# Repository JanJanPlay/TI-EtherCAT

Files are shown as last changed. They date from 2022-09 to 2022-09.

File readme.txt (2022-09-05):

Please run the zip installer to obtain the below

 #1. SSC Tool Patches for C28x
		Note:- ETG SSC Tool patches for C28x MCU. This needs to be used if the SSC tool doesn't by default support the C28x config

 #2. Out of box Demo OUT file(s) 
		Note:- User will need to program the binary/COFF files on the ESC. 

Important Note:-

TMDSECATCNCD379D_EtherCAT_Solution_Ref
  - Please refer to SPRUIG9 user guide before building this CCS (Code Composer Studio) project.

  - Please note that this project will be built successfully only after user generates the EtherCAT slave stack sources using SSC tool and patches provided and moves them into the project. 
   The steps are explained in the SPRUIG9 user guide.

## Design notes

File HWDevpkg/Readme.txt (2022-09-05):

Release notes for Hardware files TMDSECATCNCD379D_V1.0
Date:- 09/30/2017.

This release requires two sets of Hardware board design.

EcAT adapter design includes in this folder 

and

Refer to the F28379D development kit folder for Controlcard design files

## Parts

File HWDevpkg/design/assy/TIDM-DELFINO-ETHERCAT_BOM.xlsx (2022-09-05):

Item | P/N | Vendor | Qty | Unit | ION Footprint | Type | Rev | Stat | Title | Detail | Mfr Name | Reference(m) | Reference(t) | Mfr P/N
1 | 518081-0001R |  | 1 | each |  | DWG | C | U | PWB,BOOSTXL-ETHERCAT | CSTM
2 | 518082-0001 |  | 1 | each |  | DOC | C | U | LOGIC,BOOSTXL-ETHERCAT | SCH
5 | 104671-0001R-TI |  | 1 | each | bga128-8mm | PS |  | U | IC,BGA128,.8mm,ETHERCAT SLAVE CONTROLLER | MATL | Beckhoff | U5 |  | ET1100
6 | 104684-0001R |  | 2 | each | VQFN32_202SQ | PS |  | U | IC,QFN32,SINGLE PORT 10/100Mbs ETHERNET PHY TRANSCEIVER,LOW POWER | MATL | Texas Instruments | U3, U6 |  | PDP83822RHBT
7 | 101670-0001R |  | 1 | each | tssop16-14x70 | PS |  | U | IC,QSOP16,LOW VOLTAGE,QUAD 2:1 MULTIPLEXER/DEMULTIPLEXER | MATL | Texas Instruments | U7 |  | SN74CBTLV3257PWR
8 | 101659-0001R |  | 1 | each | dbq20-14x70 | PS |  | U | IC,QSOP20,LOW VOLTAGE,QUICK SWITCH | MATL | Texas Instruments | U2 |  | SN74CBTLV3245ADBQR
9 | 101057-0007R |  | 1 | each | dck-5 | PS |  | U | IC,SO5,SINGLE BUFFER/DRIVER | MATL | Texas Instruments | U1 |  | SN74LVC1G07DCKR
10 | 104686-0001R |  | 1 | each | so8-25x75-295 | PS |  | U | IC,SO8,SERIAL EEPROM,16K-BIT | MATL | Catalyst Semiconductor, Inc. | U4 |  | CAT24C16WI-GT3
11 | 104063-0001R |  | 1 | each | dsg8-11x20 | PS |  | U | IC,SON8,STEP-DOWN DC-DC CONVERTER,1.6A,3.3V | MATL | Texas Instruments | U8 |  | TPS62063DSGT
14 | 103274-0025R |  | 1 | each | xtal4-47x51-ecx32 | PS |  | U | CRYSTAL,SMT,4 PIN,25MHz | MATL | ECS | Y1 |  | ECS-250-20-33-TR
15 | 100823-0001R |  | 2 | each | led1206-59x59 | PS |  | U | LED,SMT 1206,GREEN | MATL | LITEON | DS1, DS2 |  | LTST-C150GKT
16 | 104075-0100R |  | 1 | each | ind-LQH44p | PS |  | U | INDUCTOR,SMT,1uH | MATL | Murata Electronics | L2 |  | LQH44PN1R0NP0L
20 | 101858-2201R |  | 1 | each | l603-35x45 | PS |  | U | FERRITE BEAD,SMT 0603,220 OHM | MATL | Murata Electronics | L1 |  | BLM18AG221SN1D
25 | 103604-1472R |  | 2 | each | C1206-40X70 | PS |  | U | CAP,CER,SMT 1206,4700pF,200V,+10/-10%,X7R | MATL | AVX Corporation | C41, C83 |  | 12062C472KAT2A
26 | 101064-0221R |  | 2 | each | C1206-40X70 | PS |  | U | CAP,CER,SMT 1206,22uF,10V | MATL | Taiyo Yuden | C4, C6 |  | LMK316F226ZL-T
27 | 101007-0100R |  | 8 | each | c603-35x45 | PS |  | U | CAP,CER,SMT 0603,1uF,6.3V,X5R,+/-10% | MATL | Murata Electronics | C12, C14, C15, C33, C55, C58, C77, C82 |  | GRM188R60J105KA01D
28 | 102963-0101R |  | 8 | each | c603-35x45 | PS |  | U | CAP,CER,SMT 0603,10uF,6.3V,X5R,+/-20% | MATL | Murata Electronics | C22, C26, C34, C38, C44, C74, C78, C80 |  | GRM188R60J106ME47D
29 | 101782-1223R |  | 15 | each | c402-25 | PS |  | U | CAP,CER,SMT 0402,220pF,50V,NPO | MATL | Murata Electronics | C2, C27, C28, C30, C31, C43, C46, C49, C52, C57, C63, C64, C66, C67, C81 |  | GRM1555C1H221JA01D
30 | 101782-1154R |  | 2 | each | c402-25 | PS |  | U | CAP,CER,SMT 0402,15pF,50V,NPO | MATL | Yageo | C3, C7 |  | CC0402JRNPO9BN150
31 | 101782-1103R |  | 2 | each | c402-25 | PS |  | U | CAP,CER,SMT 0402,100pF,50V,+/-5%,NPO | MATL | Kemet Electronics Corporation | C1, C37 |  | C0402C101J5GAC
32 | 101782-1102R |  | 5 | each | c402-25 | PS |  | U | CAP,CER,SMT 0402,1000pF,50V,+/-5%,NPO | MATL | TDK Corporation | C8, C25, C32, C73, C76 |  | CGJ2B2C0G1H102J
33 | 104446-1100R |  | 35 | each | c402-25 | PS |  | U | CAP,CER,SMT 0402,.1uF,16V,+/-10%,X7R,AUTOMOTIVE | MATL | Murata Electronics | C5, C9, C10, C11, C13, C16, C17, C19, C20, C21, C23, C29, C35, C36, C39, C40, C42, C45, C47, C48, C50, C51, C53, C54, C56, C59, C60, C62, C65, C68, C69, C70, C71, C75, C79 |  | GCM155R71C104KA55
34 | 101587-1101R |  | 4 | each | c402-25 | PS |  | U | CAP,CER,SMT 0402,.01uF,16V,+/-10%,X7R | MATL | Kemet Electronics Corporation | C18, C24, C61, C72 |  | C0402C103K4RAC
40 | 103158-2202R |  | 18 | each | r201-6p6spc | PS |  | U | RES,SMT 0201,2.2K OHM,5%,1/20 WATT | MATL | Yageo | R15, R16, R17, R22, R30, R32, R36, R37, R41, R48, R49, R50, R52, R54, R57, R62, R63, R69 |  | RC0201JR-072K2L
41 | 101370-0001R |  | 2 | each | r402-25 | PS |  | U | RES,SMT 0402,0 OHM,1/16 WATT | MATL | Yageo | RJ1, RJ2 |  | RC0402JR-070RL
42 | 102145-1003R |  | 2 | each | r402-25 | PS |  | U | RES,SMT 0402,10K,1%,1/16 WATT | MATL | Yageo | R1, R8 |  | RC0402FR-0710KL
43 | 102145-1103R |  | 1 | each | r402-25 | PS |  | U | RES,SMT 0402,11K OHM,1%,1/16 WATT | MATL | Panasonic | R19 |  | ERJ-2RKF1102X
44 | 102145-4702R |  | 20 | each | r402-25 | PS |  | U | RES,SMT 0402,4.7K,1%,1/16 WATT | MATL | Vishay Intertechnology | R13, R18, R20, R24, R25, R26, R27, R28, R33, R34, R42, R44, R45, R46, R47, R59, R66, R67, R68, R73 |  | CRCW04024K70FKED
45 | 102145-4872R |  | 2 | each | r402-25 | PS |  | U | RES,SMT 0402,4.87K,1%,1/16 WATT | MATL | Panasonic | R40, R65 |  | ERJ-2RKF4871X
46 | 102145-4990R |  | 14 | each | r402-25 | PS |  | U | RES,SMT 0402,49.9 OHM,1%,1/16 WATT | MATL | Panasonic | R2, R3, R4, R5, R6, R7, R9, R10, R11, R12, R39, R58, R70, R71 |  | ERJ-2RKF49R9X
47 | 100687-4701R |  | 6 | each | r603-35X45 | PS |  | U | RES,SMT 0603,470 OHM,5%,1/16 WATT | MATL | Panasonic | R14, R43, R51, R72, R74, R75 |  | ERJ-3GEYJ471V
50 | 101184-0002R |  | 1 | each | sw2-30x50-tda | PS |  | U | SWITCH,DIP,SMT,HALF-PITCH,2 POS. | MATL | C&K/Unimax, Inc. | SW1 |  | TDA02H0SB1R
55 | 104687-0060R |  | 1 | each | df40c_60ds | PS |  | U | CONN,SMT,RECEPTACLE,60 POS.,.4mm SPC.,4mm STACKING HEIGHT | MATL | Hirose Electric, Inc. | J6 |  | DF40HC-(4.0)60DS-0.4V
57 | 104401-0001R |  | 2 | each | RJ45-PULSE_J1-SHLD | PS |  | U | CONN,JACK,RJ45,INTEGRATED MAGNETICS AND LED'S,8 CONTACTS,SHIELDED | MATL | Pulse Engineering | P1, P0 |  | J1011F01PNL
58 | 100546-0003R |  | 2 | each | hdr1x3-6040-2mm | PL |  | U | HEADER,3 X 1,VERTICAL,2mm | SUBA | Harwin | J3, J10 |  | M22-2510305
60 | 104178-0001R |  | 1 | each | TP1-70X135 | PS |  | U | TEST POINT,SMT,MINIATURE | MATL | Keystone Electronics Corp. | TP15 |  | 5015
65 | SMT-TP030 |  | 11 | each | tp30 | PS |  | U | ( NO-POP ) TEST POINT,SMT,.03" DIA. | NP | None | TP2, TP3, TP4, TP5, TP6, TP7, TP9, TP11, TP13, TP14, TP16 |  | None
70 | R0201-NOPOP |  | 10 | each | r201-6p6spc | PS |  | U | (NO-POP) RES,SMT 0201 | NP | None | R23, R29, R31, R35, R38, R53, R55, R56, R61, R64 |  | None
75 | R0402-NOPOP |  | 2 | each | r402-25 | PS |  | U | (NO-POP) RES,SMT 0402 | NP | None | R21, R60 |  | None
80 | TP-40RD20-NO-POP |  | 4 | each | tp1-4020 | PS |  | U | (NO-POP) TEST POINT | NP | None | TP1, TP8, TP10, TP12 |  | None
81 | 104699-0002R |  | 1 | each | conn2-eh | PS |  | U | CONN,HEADER,SHROUDED,2 POS | MATL | JST Corporation | J9 |  | B2B-EH-A(LF)(SN
82 | 100542-0001R |  | 2 | each |  | PS |  | U | JUMPER,SHUNT,2mm | MATL | Sullins Electronics, Corp. |  |  | SPN02SYBN-RC

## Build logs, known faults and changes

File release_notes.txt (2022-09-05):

Release notes for Software included in TMDSECATCNCD379D_V1.0

Date:- 09/29/2017

Documents:-
	 1. SPRUIF9.pdf - HW, Demo and PDI HAL API TEST APP Getting started guide
  	 2. SPRUIG9.pdf - TMDSECATCND379D EtherCAT Solution Reference guide

Deliverables:- 

	 1. PDI HAL Test APP for TMDSECATCNCD379D 
		Note:- Code Composer Studio project

	 2. EtherCAT solution reference project 
		Note:- For users to do source level debug with ETG SSC tool generated EtherCAT slave stack sources. Before building this project please read SPRUIG9.pdf

	 3. SSC(Slave Stack code) Tool Patches for C28x
		Note:- ETG(EtherCAT Technology group) SSC Tool patches for C28x MCU. This needs to be used if the SSC tool doesn't by default support the C28x config

	 4. Out of box Demo OUT file(s) 
		Note:- User will need to program the binary/COFF files on the ESC. 
		Please read SPRUIF9 on how to use the DEMO files.

Note:- Deliverables 3 and 4 are obtained by running the zip installer available in the folder.		

EtherCAT slave stack features supported in this release:- 
	 1. COE Mailbox support for data exchange
	 2. Conformance Test Tool run on the demo application
	 3. TwinCAT EtherCAT master running on a laptop is used as EtherCAT master.
 
Build Environment:-
	Slave Stack code base line :-  v5.11
	CCS compiler version :- 16.12.x
	CTT tool version used for test :- 2.0.42.0
		Test Library version:- 1.1.0.0

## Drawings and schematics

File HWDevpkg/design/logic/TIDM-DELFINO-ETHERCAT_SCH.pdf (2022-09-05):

J10 DEFAULT JUMPER POP | 1-2
J3 DEFAULT JUMPER POP | 1-2

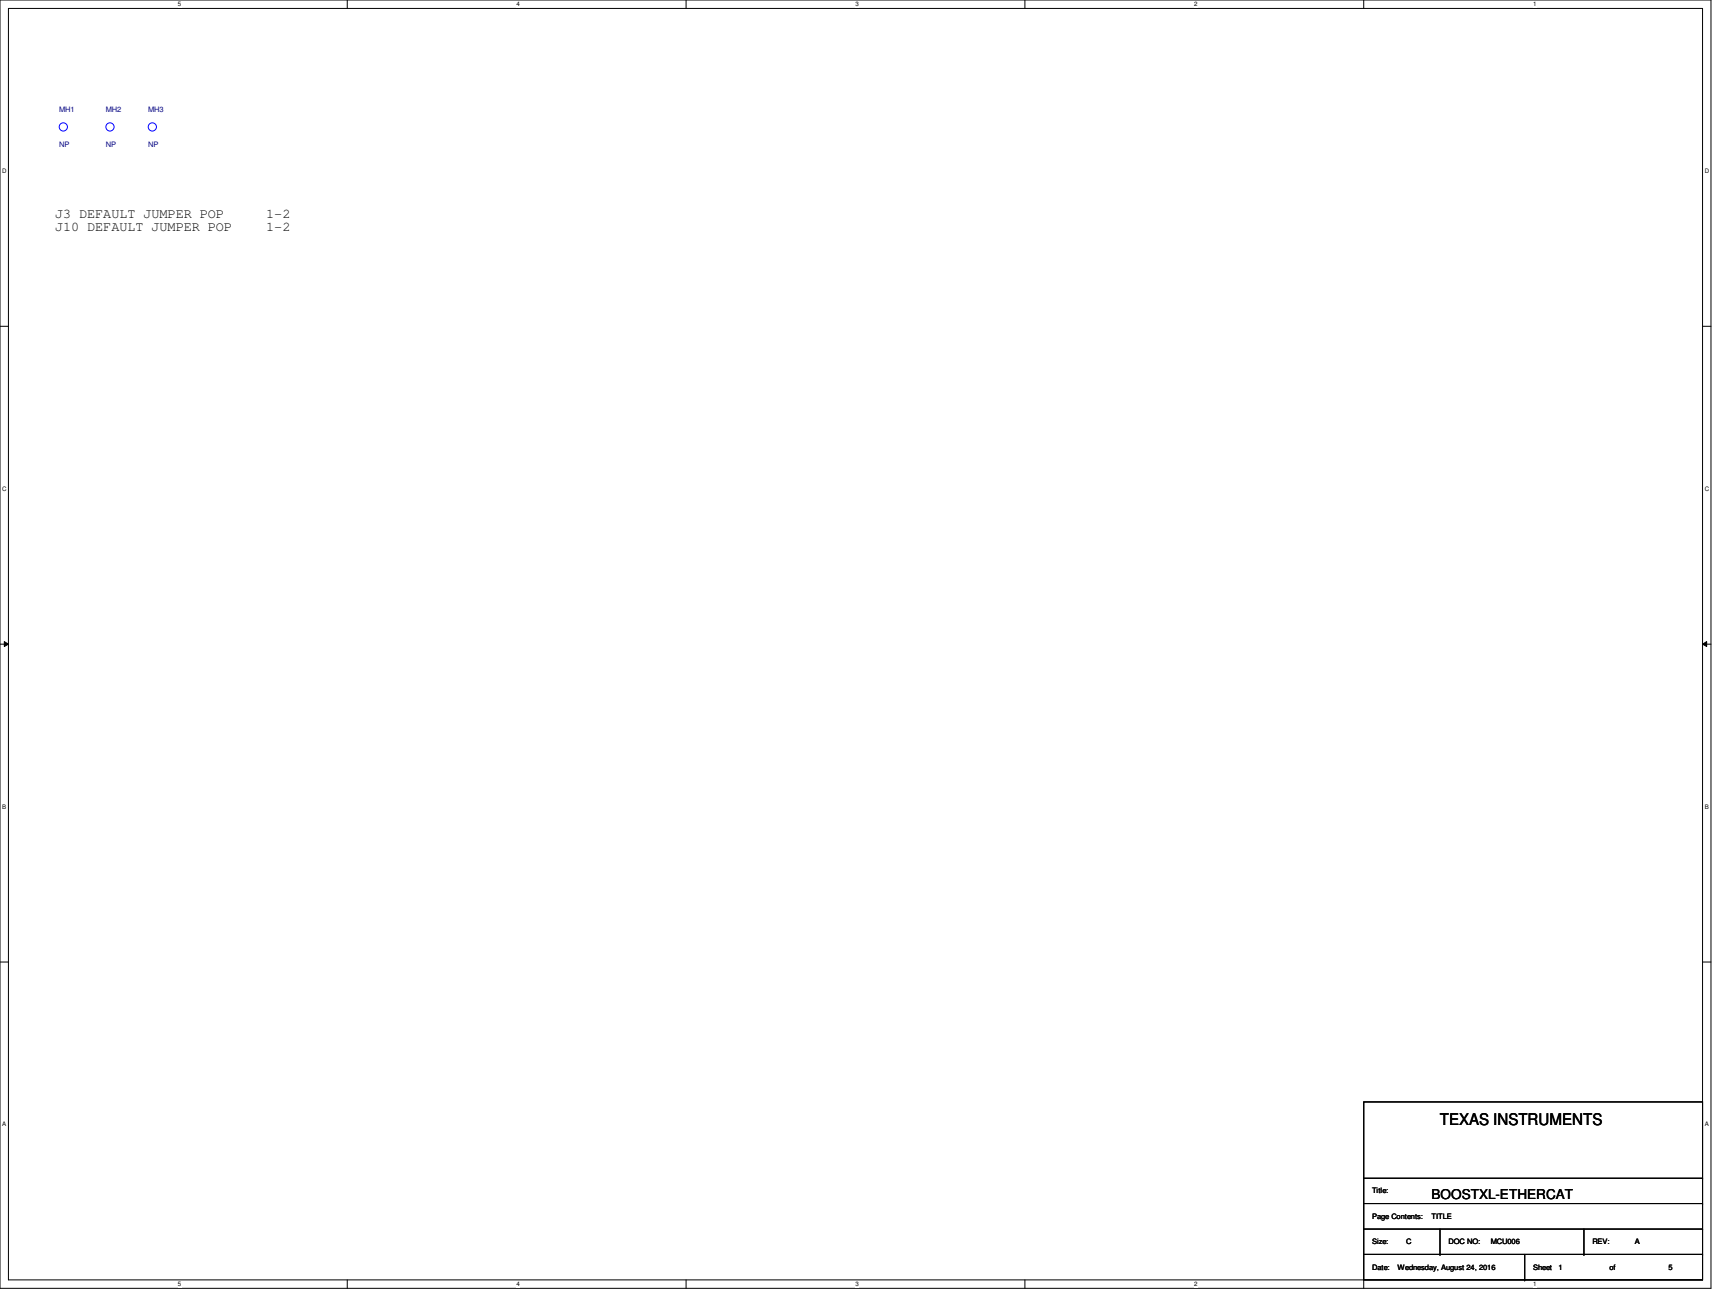
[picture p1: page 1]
Title:; Page Contents:; Size:; DOC NO:; REV:; Date:; Sheet; TEXAS INSTRUMENTS; BOOSTXL-ETHERCAT; TITLE; Wednesday, August 24, 2016; MCU006

## CONTROL CARD SPI/EMIF CONNECTIONS

## SPI vs EMIF POPULATIONS

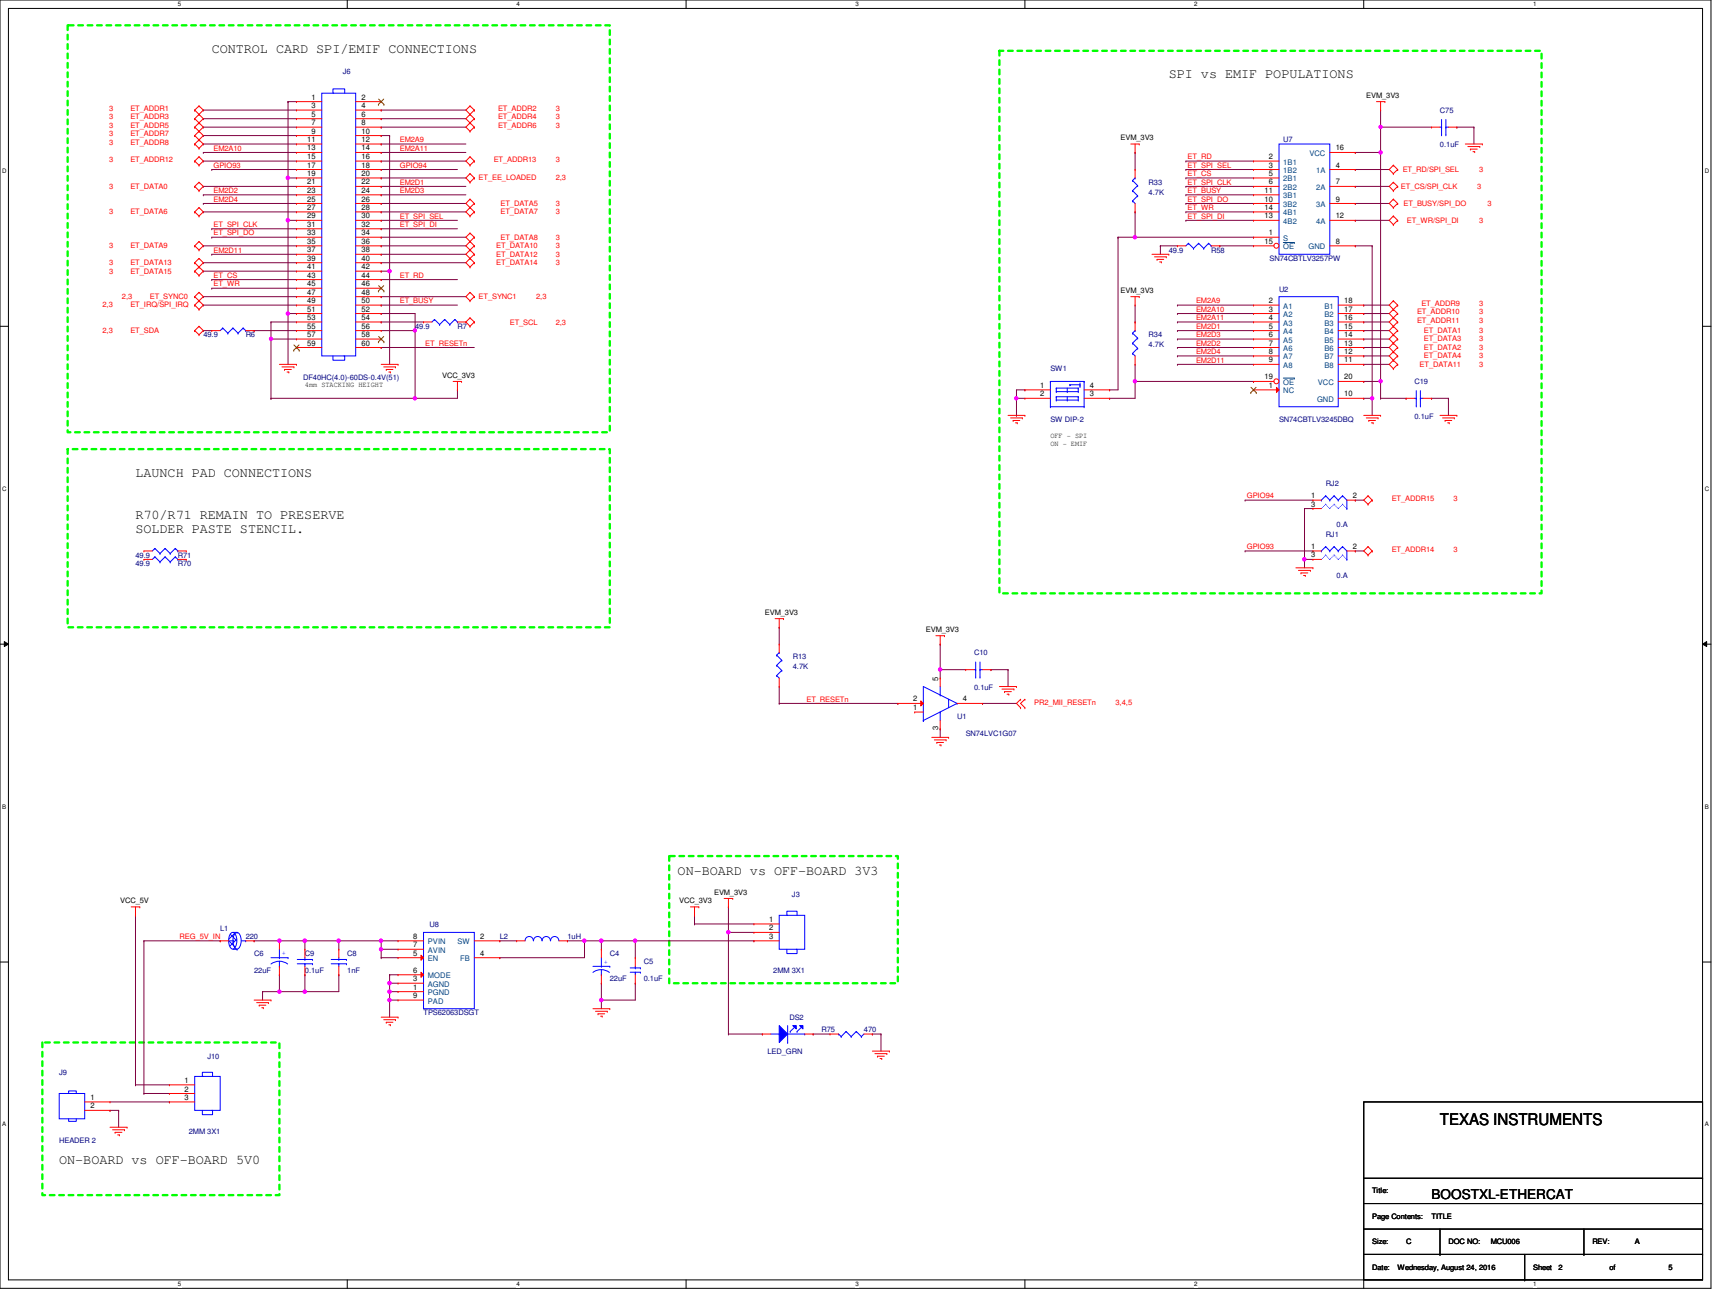
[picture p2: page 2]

ON-BOARD vs OFF-BOARD 3V3

HEADER 2
ON-BOARD vs OFF-BOARD 5V0

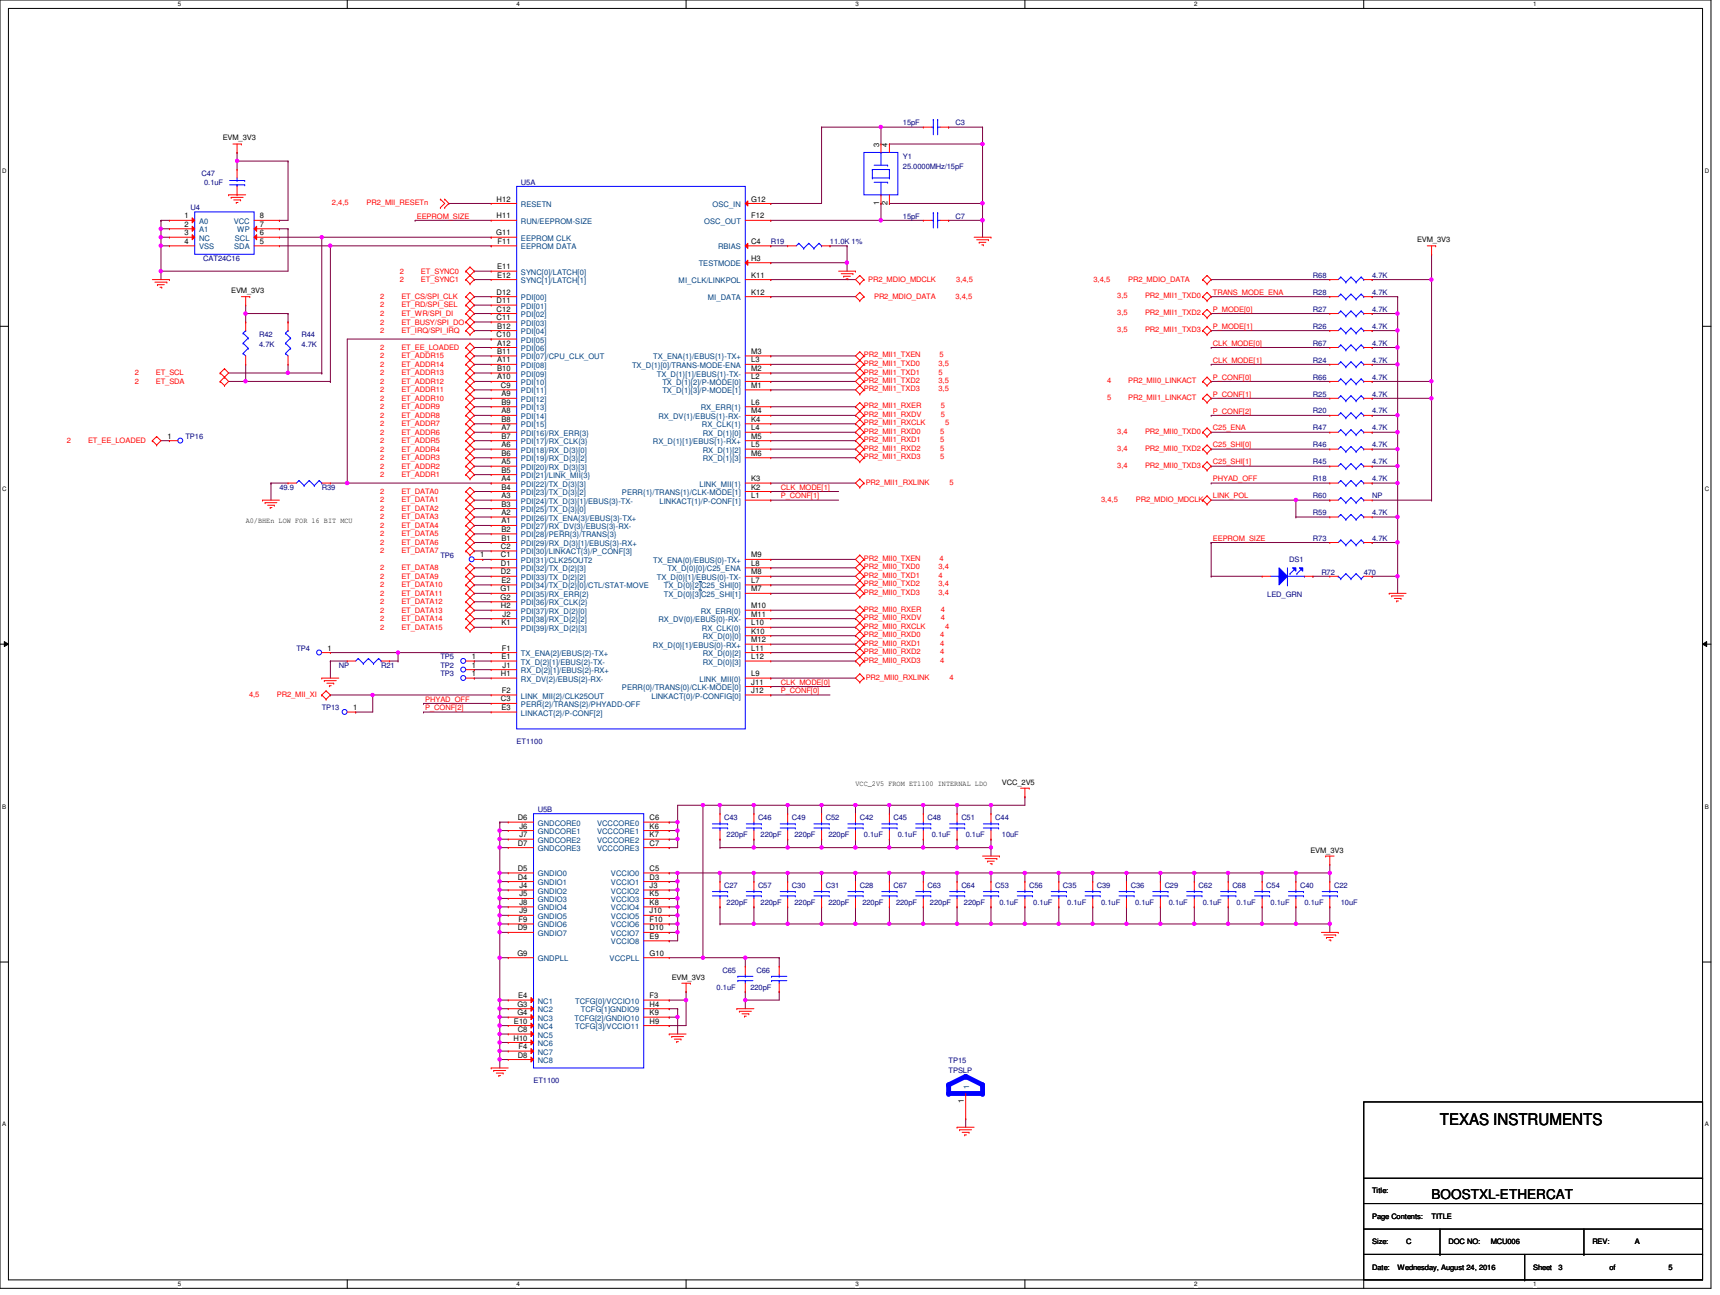
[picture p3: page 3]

A0/BHEn LOW FOR 16 BIT MCU

LINK_MII{2}/CLK25OUT F2
PERR{2}/TRANS{2}/PHYADD-OFF C3
LINKACT{2}/P-CONF[2] E3

# PORT 0: IN

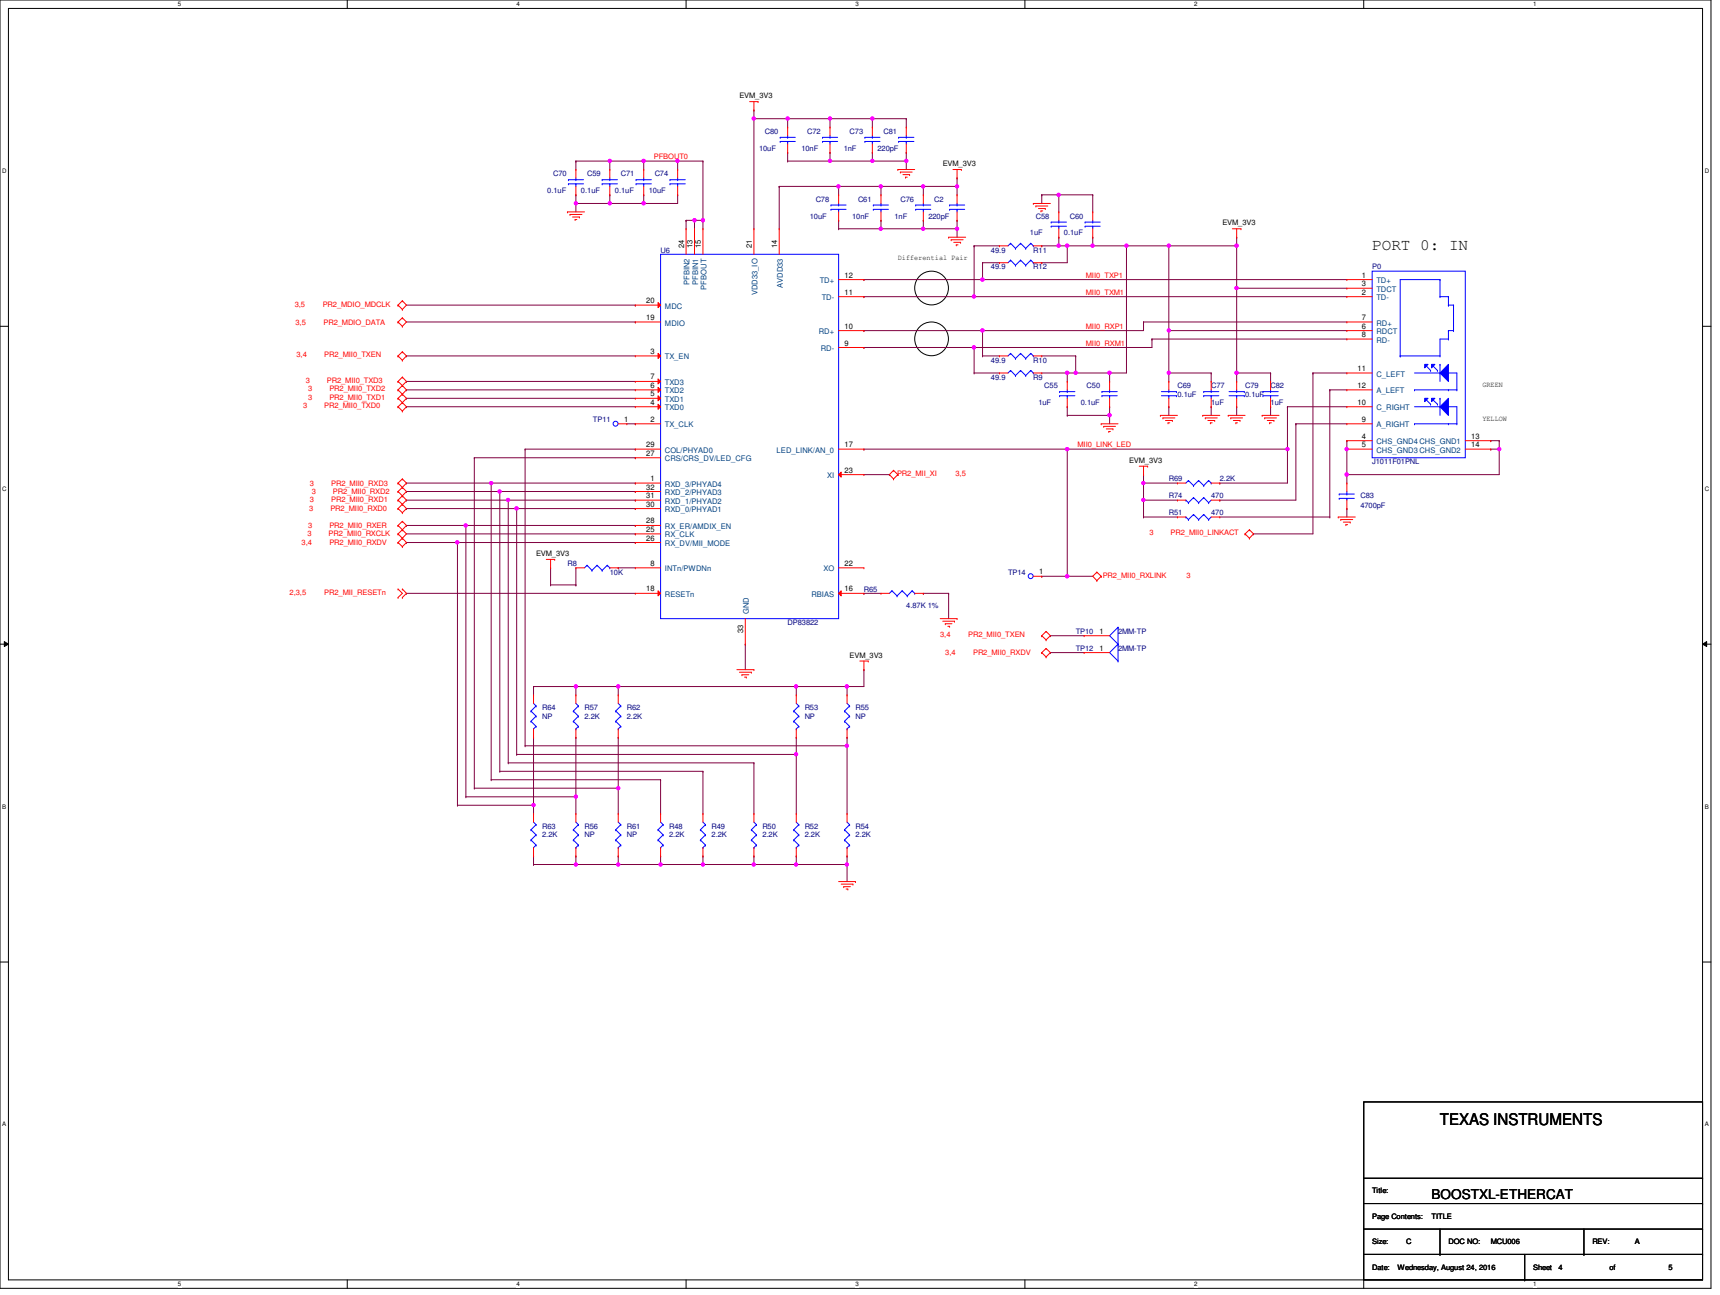
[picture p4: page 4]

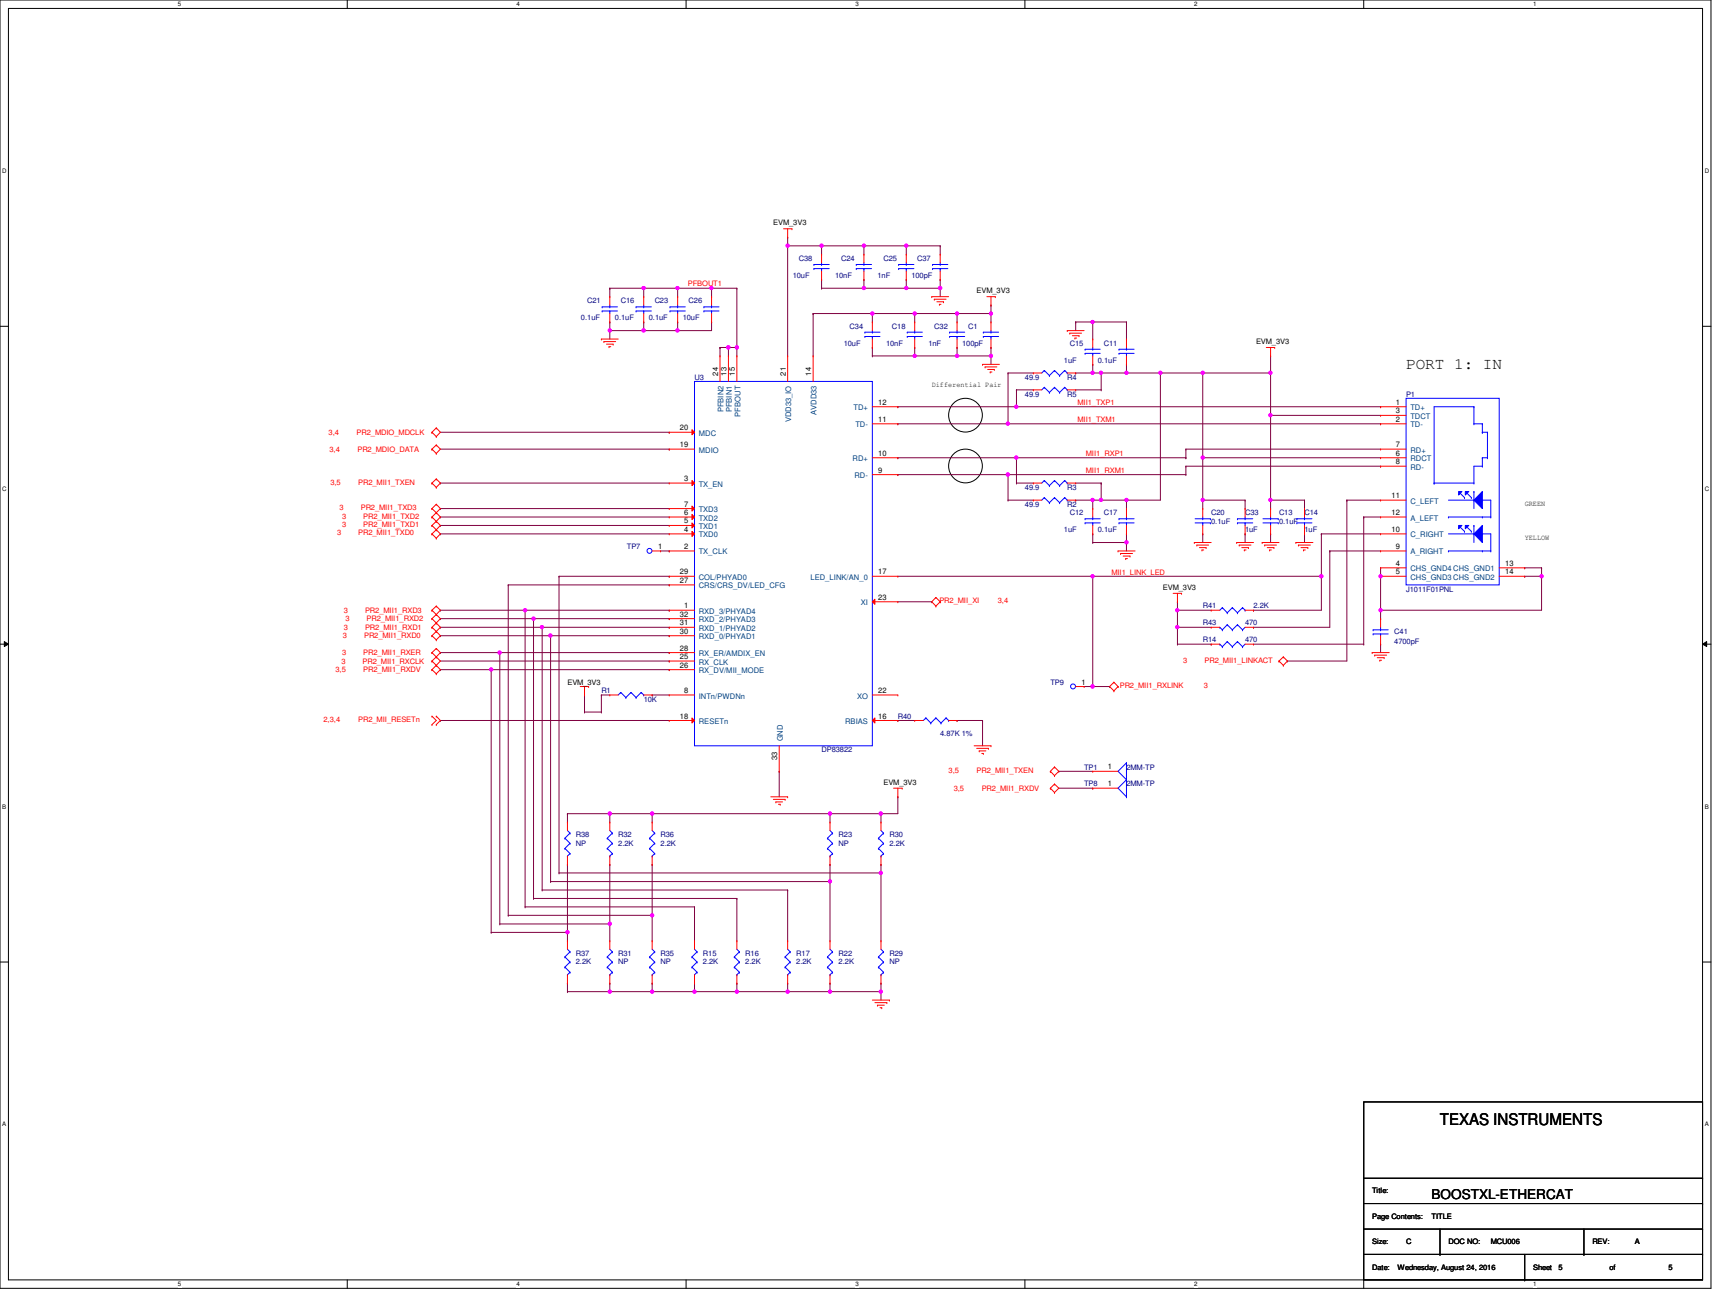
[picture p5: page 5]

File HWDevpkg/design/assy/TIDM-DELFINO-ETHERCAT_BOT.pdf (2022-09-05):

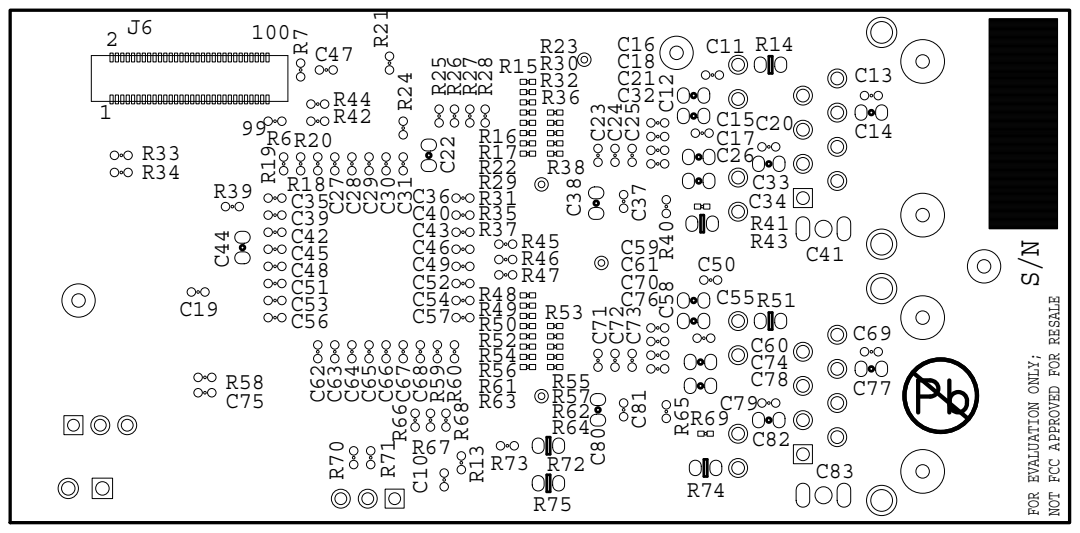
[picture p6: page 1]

NOT FCC APPROVED FOR RESALE

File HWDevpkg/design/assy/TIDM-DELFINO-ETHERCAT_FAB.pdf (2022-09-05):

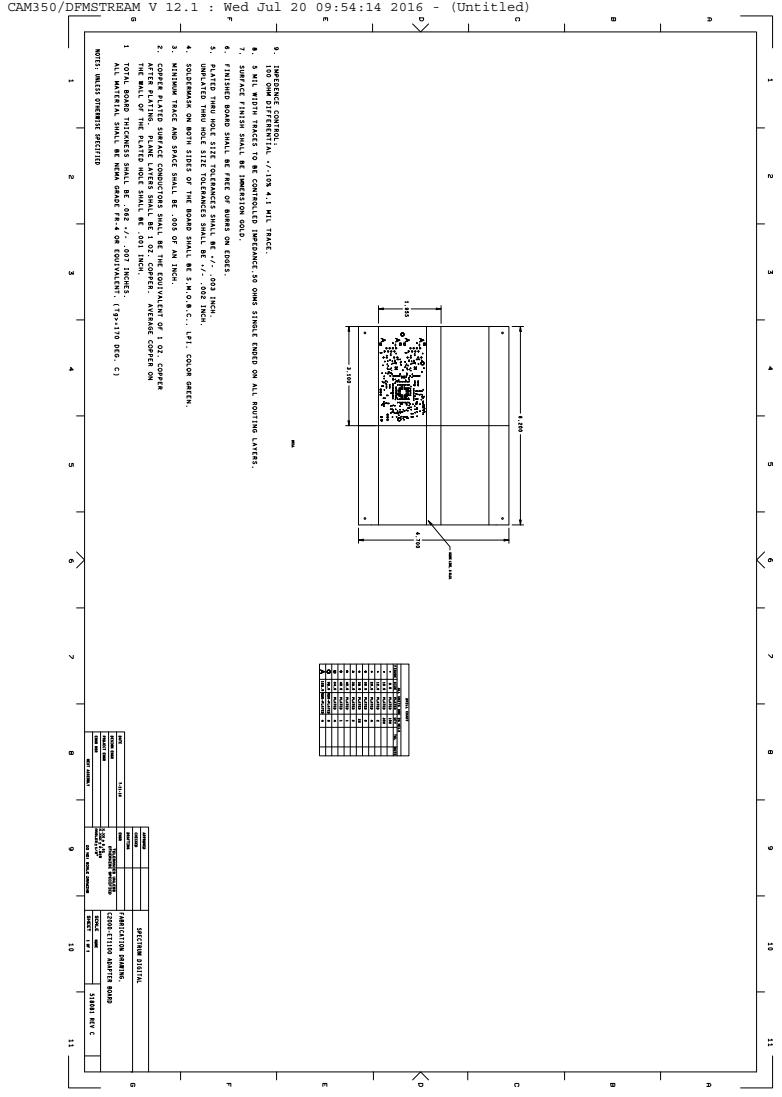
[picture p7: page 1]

CAM350/DFMSTREAM V 12.1 : Wed Jul 20 09:54:14 2016 - (Untitled)

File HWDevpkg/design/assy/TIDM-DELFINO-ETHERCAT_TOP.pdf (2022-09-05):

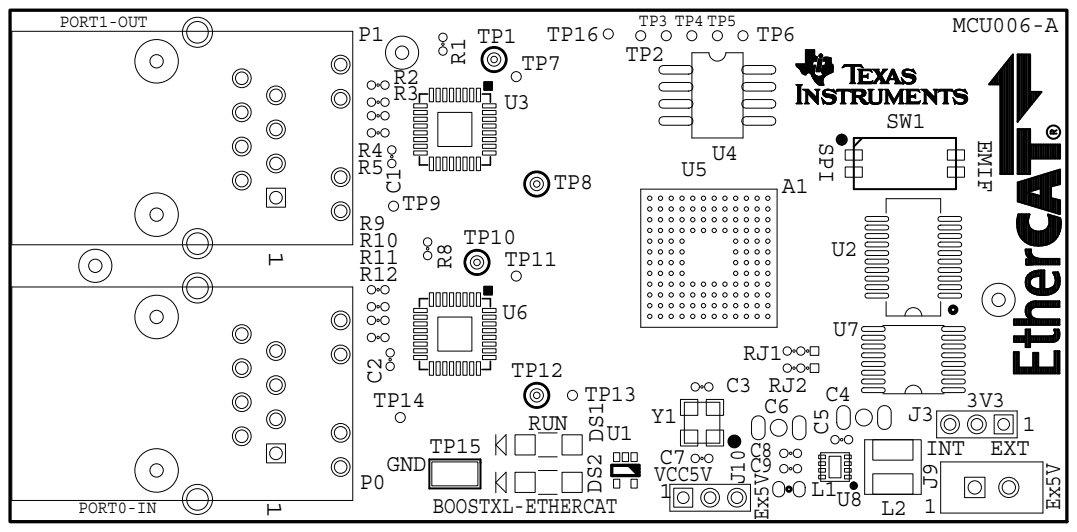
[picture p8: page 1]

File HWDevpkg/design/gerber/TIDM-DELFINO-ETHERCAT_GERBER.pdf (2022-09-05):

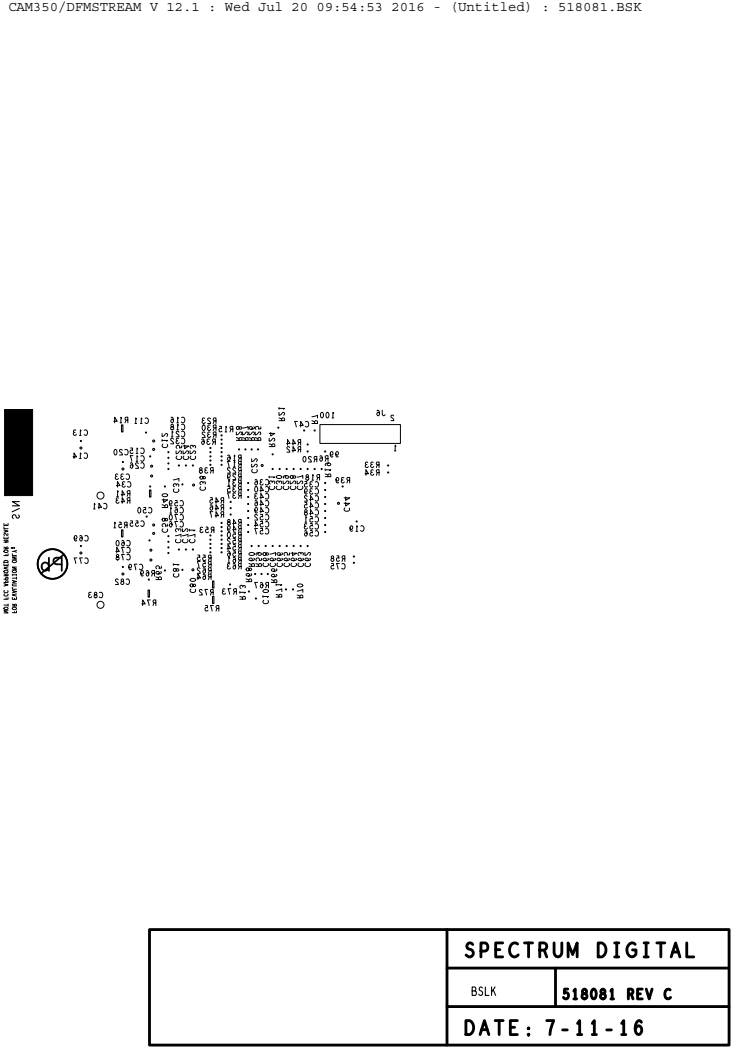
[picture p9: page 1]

CAM350/DFMSTREAM V 12.1 : Wed Jul 20 09:54:53 2016 - (Untitled) : 518081.BSK

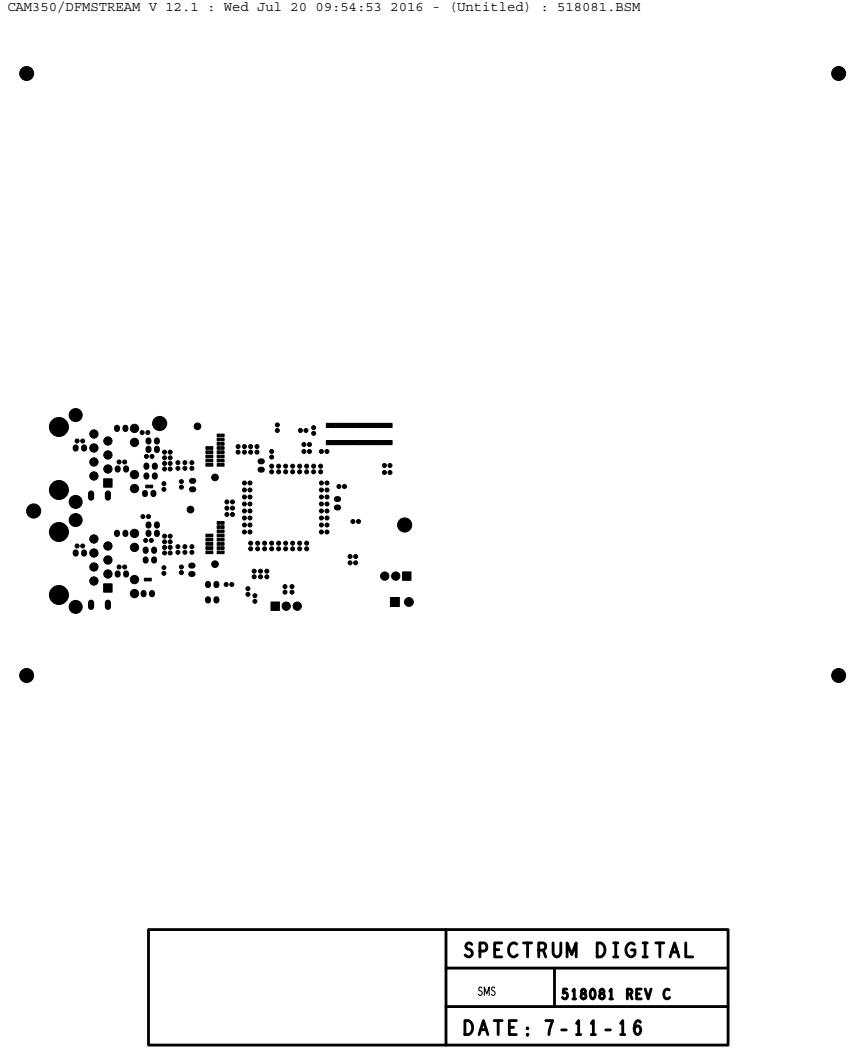
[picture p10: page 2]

CAM350/DFMSTREAM V 12.1 : Wed Jul 20 09:54:53 2016 - (Untitled) : 518081.BSM

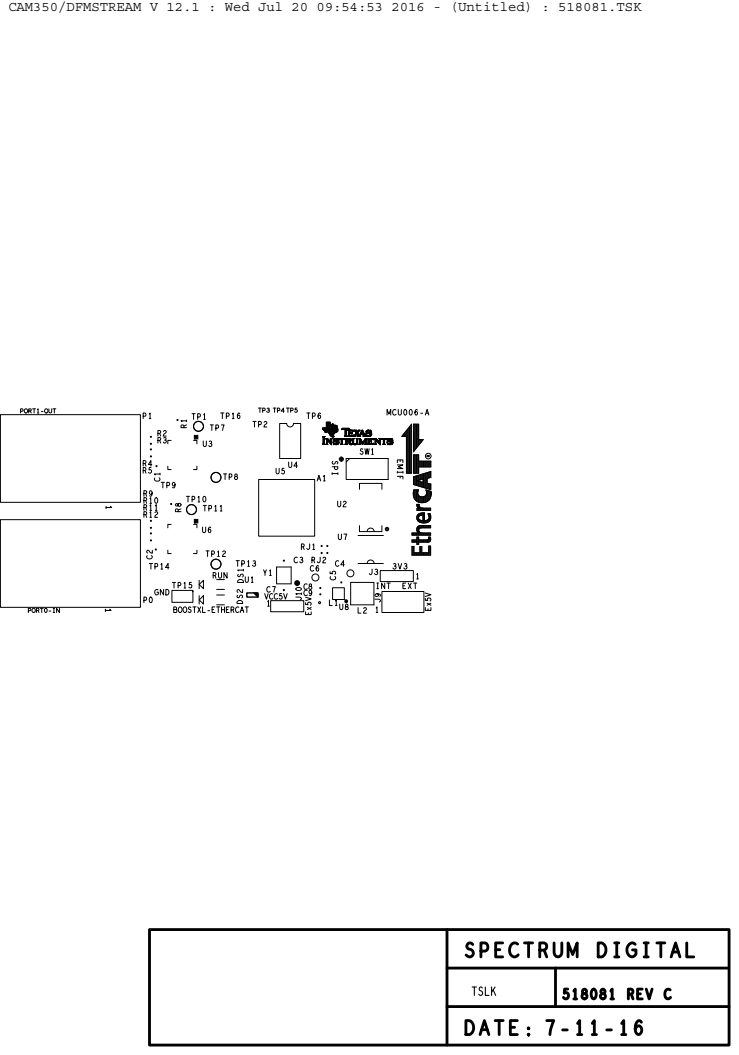
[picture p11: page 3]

CAM350/DFMSTREAM V 12.1 : Wed Jul 20 09:54:53 2016 - (Untitled) : 518081.TSK

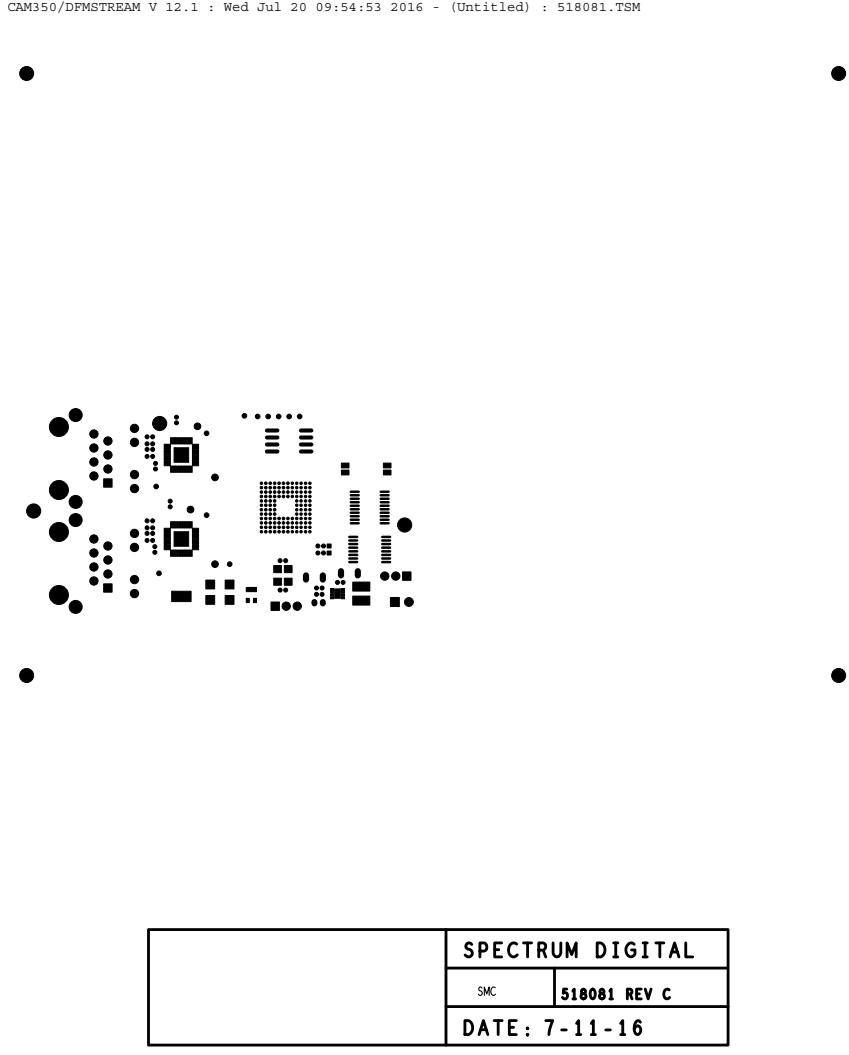
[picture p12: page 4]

CAM350/DFMSTREAM V 12.1 : Wed Jul 20 09:54:53 2016 - (Untitled) : 518081.TSM


CAM350/DFMSTREAM V 12.1 : Wed Jul 20 09:54:53 2016 - (Untitled) : 518081.bot


CAM350/DFMSTREAM V 12.1 : Wed Jul 20 09:54:53 2016 - (Untitled) : 518081.bsp


CAM350/DFMSTREAM V 12.1 : Wed Jul 20 09:54:53 2016 - (Untitled) : 518081.l2


CAM350/DFMSTREAM V 12.1 : Wed Jul 20 09:54:53 2016 - (Untitled) : 518081.l3


CAM350/DFMSTREAM V 12.1 : Wed Jul 20 09:54:53 2016 - (Untitled) : 518081.l4


CAM350/DFMSTREAM V 12.1 : Wed Jul 20 09:54:53 2016 - (Untitled) : 518081.l5


CAM350/DFMSTREAM V 12.1 : Wed Jul 20 09:54:53 2016 - (Untitled) : 518081.top


CAM350/DFMSTREAM V 12.1 : Wed Jul 20 09:54:53 2016 - (Untitled) : 518081.tsp


CAM350/DFMSTREAM V 12.1 : Wed Jul 20 09:54:53 2016 - (Untitled) : ncdrill-1-6.drl

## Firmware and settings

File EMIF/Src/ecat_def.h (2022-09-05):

/*-----------------------------------------------------------------------------------------
------	
------	ecat_def.h
------  SSC version : 5.11
-----------------------------------------------------------------------------------------*/

#ifndef _ECATDEF_H_
#define _ECATDEF_H_

/*-----------------------------------------------------------------------------------------
------	
------	Includes
------ 
-----------------------------------------------------------------------------------------*/
#include <stdlib.h>
#include <string.h>

#include "c28xxsystem.h"
/*-----------------------------------------------------------------------------------------
------	
------	Slave Sample Code Configuration Defines
------	
-----------------------------------------------------------------------------------------*/

/** 
EL9800_HW: Shall be set if the Slave code is executed on the PIC mounted on the EL9800 EtherCAT Evaluation Board.<br>
(if the MCI interface provided by EL9800 board should be used MCI_HW shall be set and this define shall be reset).<br>
This settings should also be enabled if the ESC is connected via a serial interface and no specific hardware access files are avilable yet.<br>
NOTE: The PDI type needs also to be configured in the "ESC_CONFIG_DATA". */
#ifndef EL9800_HW
#define EL9800_HW                                 0 //This define was already evaluated by ET9300 Project Handler(V. 1.3.3.0)!
#endif

/** 
MCI_HW: Shall be set if the MCI of the ESC is connected.<br>
This settings should also be enabled if the ESC is connected via a parallel interface and no specific hardware access files are avilable yet.<br>
NOTE: The PDI type needs also to be configured in the "ESC_CONFIG_DATA". */
#ifndef MCI_HW
#define MCI_HW                                    0 //This define was already evaluated by ET9300 Project Handler(V. 1.3.3.0)!
#endif

/** 
FC1100_HW: Shall be set if the EtherCAT slave controller is located on an FC1100 PCI card.<br>
NOTE: The PDI type needs also to be configured in the "ESC_CONFIG_DATA". */
#ifndef FC1100_HW
#define FC1100_HW                                 0 //This define was already evaluated by ET9300 Project Handler(V. 1.3.3.0)!
#endif

/** 
TIESC_HW: Temporary define to support TI ICE/IDK development board (Shall be set if the Slave code shall executed on an AM335X ICE/IDK Evaluation Board<br>
from Texas Instruments) */
#ifndef TIESC_HW
#define TIESC_HW                                  0 //This define was already evaluated by ET9300 Project Handler(V. 1.3.3.0)!
#endif

/** 
CONTROLLER_16BIT: Shall be set if the host controller is a 16Bit architecture */
#ifndef CONTROLLER_16BIT
#define CONTROLLER_16BIT                          1 //This define was already evaluated by ET9300 Project Handler(V. 1.3.3.0)!
#endif

/** 
CONTROLLER_32BIT: Shall be set if the host controller is a 32Bit architecture */
#ifndef CONTROLLER_32BIT
#define CONTROLLER_32BIT                          0 //This define was already evaluated by ET9300 Project Handler(V. 1.3.3.0)!
#endif

/** 
_PIC18: Microchip PIC18F452 Specific Code <br>
This processor is mounted on the Beckhoff Slave Evaluation Board (Hardware version up to EL9800_2). */
#ifndef _PIC18
#define _PIC18                                    0 //This define was already evaluated by ET9300 Project Handler(V. 1.3.3.0)!
#endif

/** 
_PIC24: Microchip PIC24HJ128GP306 Specific Code <br>
This processor is mounted on the Beckhoff Slave Evaluation Board (Hardware version up to EL9800_4A). */
#ifndef _PIC24
#define _PIC24                                    0 //This define was already evaluated by ET9300 Project Handler(V. 1.3.3.0)!
#endif

/** 
ESC_16BIT_ACCESS: If the microcontroller only supports 16Bit access to the ESC. */
#ifndef ESC_16BIT_ACCESS
#define ESC_16BIT_ACCESS                          1 //This define was already evaluated by ET9300 Project Handler(V. 1.3.3.0)!
#endif

/** 
ESC_32BIT_ACCESS: If the microcontroller only supports 32Bit access to the ESC. */
#ifndef ESC_32BIT_ACCESS
#define ESC_32BIT_ACCESS                          0 //This define was already evaluated by ET9300 Project Handler(V. 1.3.3.0)!
#endif

/** 
MBX_16BIT_ACCESS: If the microcontroller only supports 16Bit access to local mailbox memory(access to ESC DPRAM is controlled by "ESC_16BIT_ACCESS"). If reset 8Bit access is used. */
#ifndef MBX_16BIT_ACCESS
#define MBX_16BIT_ACCESS                          1 //This define was already evaluated by ET9300 Project Handler(V. 1.3.3.0)!
#endif

/** 
BIG_ENDIAN_16BIT: If the microcontroller always make 16 bit access to external memory, operates in BigEndian format<br>
and the switching of the high and low byte is done in hardware. */
#ifndef BIG_ENDIAN_16BIT
#define BIG_ENDIAN_16BIT                          0 //This define was already evaluated by ET9300 Project Handler(V. 1.3.3.0)!
#endif
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

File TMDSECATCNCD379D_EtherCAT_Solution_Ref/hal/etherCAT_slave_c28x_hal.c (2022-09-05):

//#############################################################################
//
// FILE:   ethercat_slave_c28x_hal.c
//
// TITLE:  C28x HAL level functions for EtherCAT slave controller (ESC)
//
//! \addtogroup C2k_EtherCAT_adapater_examples_list
//! <h1> PDI Interface test Example </h1>
//!
//! The functions in this file provide a HAL layer interface for EtherCAT slave
//! applications that can be built on C2k EtherCAT adapter board
//!
//! The HAL could be EMIF or SPI based depending on the PDI interface chosen
//! or configured for the C2k ET1100 EtherCAT adapater board
//!
//!-----------------------------------------------------------------------------
//! C28x Addressing vs. TwinCat3 software addresses for EMIF PDI
//!   The C28x address used below is a WORD (16b) address for the ET1100 PDI
//!   interface, while Beckhoff EtherCAT documentation and TwinCat3 software use
//!   BYTE addresses. The USER RAM on the ET1100 starts at 0x1000 offset BYTE
//!   address. Divide this by 2 to get the correct 16b word offset from EMIF2
//!   start address
//!
//!  EMIF PDI reads two bytes at a time from ET1100 address space, that is the
//!  minimum data size thats readable by C28x CPU
//!------------------------------------------------------------------------------
//!------------------------------------------------------------------------------
//! C28x Addressing vs. TwinCat3 software addresses for SPI PDI
//!   For the SPI PDI the addressing of ET1100 memory space is straight forward
//!   The SPI PDI uses 8 bit character length for SPI reads/writes but the HAL API
//!   is adjusted to read 16bits at a time to be consistent with the EMIF PDI.
//!   Users can modify the SPI PDI to read/write one byte at a time from ET1100
//!   address space. But since C28x data bus is 16 bit wide this example shows
//!   16bit SPI PDI reads/writes as well.
//!
//!   SPI MISO pin read for error status on the last transaction is not supported
//!      in this HAL
//!   SPI MODE 3 is supported by this HAL
//!   I0 and I1 byte reads on the MISO pin are ignored in this HAL
//!------------------------------------------------------------------------------
//! \b External \b Connections \n
//!  Users can connect a PC running TWINCAT3 to the Ethercat Slave and view the
//!  memory window of ET1100 for both registers and ET1100 RAM
//!
//! \b Watch \b Variables \n
//!  - escRegs data structure is filled in with some ET1100 registers which can be
//!    viewed in memory window if HAL Test is enabled.
//!
//!
////###########################################################################
// $TI Release: C2000 EtherCAT solutions support v1.00 $
// $Release Date: 07/2017 $
// $Copyright:
// Copyright (C) 2017 Texas Instruments Incorporated - http://www.ti.com/
//
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
//   Redistributions of source code must retain the above copyright
//   notice, this list of conditions and the following disclaimer.
//
//   Redistributions in binary form must reproduce the above copyright
//   notice, this list of conditions and the following disclaimer in the
//   documentation and/or other materials provided with the
//   distribution.
//
//   Neither the name of Texas Instruments Incorporated nor the names of
//   its contributors may be used to endorse or promote products derived
//   from this software without specific prior written permission.
//
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
//
// Included Files
//
#include "F28x_Project.h"     // Device Headerfile and Examples Include File
#include "F2837xD_spi.h"
#include "ethercat_slave_c28x_hal.h"

//
// Defines
//
//#define ETHERCAT_STACK  1   //only use if EtherCAT slave stack is used

//
//globals
//

//Pointer to the ESC memory, initialized in the ESC_initHW()
//used only for the ASYNC16 (EMIF1 or EMIF2) PDI
uint16_t *pEsc;

#ifdef PDI_HAL_TEST
//Debug array to log esc registers, used only for PDI HAL TEST
esc_et1100_regs_t escRegs[ESC_DEBUG_REGS_LENGTH];
#endif

#ifdef INTERFACE_SPI
// SPI Variables
volatile uint16_t   SPI_RxData[16];     // Receive data buffer
volatile uint16_t   SPI_XmitInProgress;
#endif


//
//HAL level functions
//
#ifndef __cplusplus

#ifdef INTERFACE_SPI
#pragma CODE_SECTION(ESC_readSPI, ".TI.ramfunc");
#pragma CODE_SECTION(ESC_writeSPI, ".TI.ramfunc");
#endif
#pragma CODE_SECTION(ESC_timerIncPerMilliSec, ".TI.ramfunc");
#pragma CODE_SECTION(ESC_getTimer, ".TI.ramfunc");
#endif

/***********************************************************************************/

uint32_t ESC_getTimer(void)
{
    //C28x timer is decrements from 0xFFFFFFFF while the stack understands it as of 
    //increment type. 
    return ~ ((uint32_t)(CpuTimer0Regs.TIM.all));
}
/***********************************************************************************/
void ESC_clearTimer(void)
{
    CpuTimer0Regs.TIM.all = 0;
}
/***********************************************************************************/
uint32_t ESC_timerIncPerMilliSec(void)
{
    return (uint32_t) 200000UL; //at 200MHz
}
/***********************************************************************************/
#ifdef INTERFACE_SPI
//
// SPI HAL functions for EtherCAT slave stack
//

//SPI peripehral register pointer, will be initialized depending on the SPI chosen as per
// build configurations
volatile struct SPI_REGS *SpixRegs;
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
